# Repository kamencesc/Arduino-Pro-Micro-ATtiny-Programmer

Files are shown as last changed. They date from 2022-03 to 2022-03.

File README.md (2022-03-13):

# Arduino Pro Micro ATtiny85 Programmer
Board to program ATtiny85 using an Arduino Pro Micro.

It fits on two diferent size of Pro Micro (you can differenciate them by the USB, Mini USB for the big one and Micro USB for the little one).

Project comes from [Programming ATtiny85 with Arduino Uno ](https://create.arduino.cc/projecthub/arjun/programming-attiny85-with-arduino-uno-afb829) and it's adapted to Arduino Pro Micro, maybe needs some code modification (todo).

There are *OPTIONAL* LEDs as you can see in ~~[Utiliza tu placa Arduino como programador para ATtiny](https://fabricadigital.org/tutoriales/utiliza-tu-placa-arduino-como-programador-para-attiny/)~~ [Arduino as ISP and Arduino Bootloaders](https://docs.arduino.cc/built-in-examples/arduino-isp/ArduinoISP).

|LED|COLOR|FUNTION|
| -- | -- | -- |
|Top|Green|Heartbeat|
|Middle \*|Red|Error|
|Bottom \*|Yellow|Programming|

\* optional

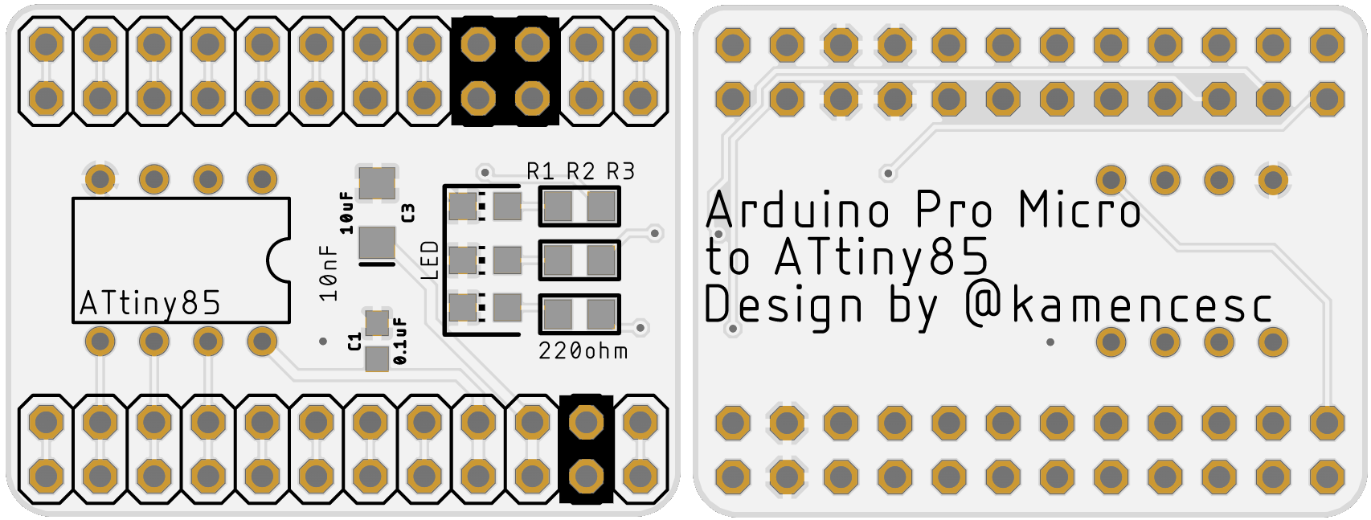
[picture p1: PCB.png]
PCB


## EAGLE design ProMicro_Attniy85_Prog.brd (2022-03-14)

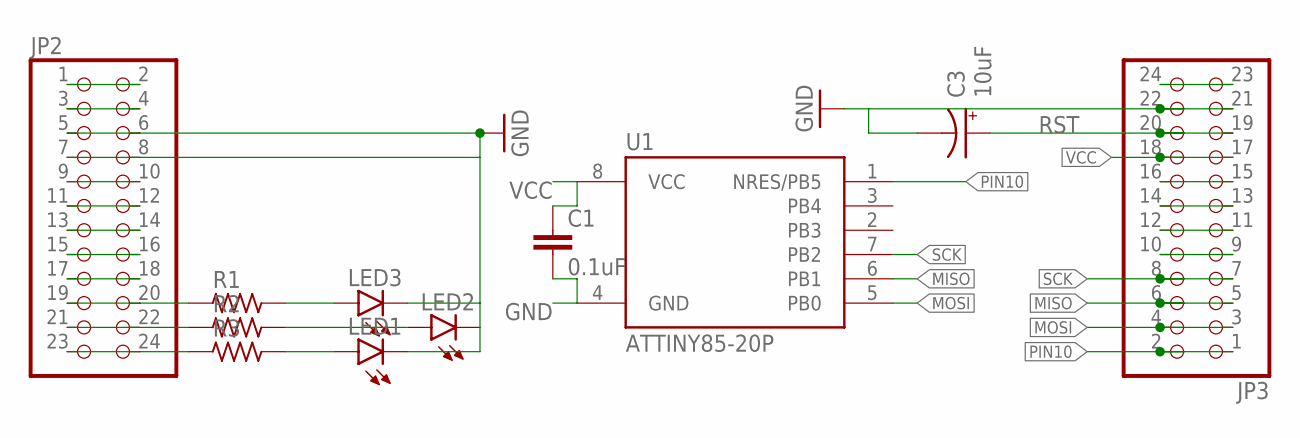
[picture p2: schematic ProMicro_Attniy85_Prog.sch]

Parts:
C1: 0.1uF; 0603
C3: 10uF; EIA3216
JP2, JP3: PINHD-2X12; 2X12
LED1, LED2, LED3: LEDCHIP-LED0805; CHIP-LED0805
R1, R2, R3: R_0805; R0805
U1: ATTINY85-20P; PDIP08_300MIL

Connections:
GND: C1.2, C3.-, JP2.5, JP2.6, JP2.7, JP2.8, JP3.21, JP3.22, LED1.C, LED2.C, LED3.C, U1.4 (GND)
MISO: JP3.5, JP3.6, U1.6 (PB1)
MOSI: JP3.3, JP3.4, U1.5 (PB0)
unnamed: JP2.1, JP2.2
unnamed: JP2.3, JP2.4
unnamed: JP2.9, JP2.10
unnamed: JP2.11, JP2.12
unnamed: JP2.13, JP2.14
unnamed: JP2.15, JP2.16
unnamed: JP2.17, JP2.18
unnamed: LED3.A, R1.2
unnamed: LED2.A, R2.2
unnamed: LED1.A, R3.2
unnamed: JP3.9, JP3.10
unnamed: JP3.11, JP3.12
unnamed: JP3.13, JP3.14
unnamed: JP3.15, JP3.16
unnamed: JP3.23, JP3.24
PIN7: JP2.19, JP2.20, R1.1
PIN8: JP2.21, JP2.22, R2.1
PIN9: JP2.23, JP2.24, R3.1
PIN10: JP3.1, JP3.2, U1.1 (NRES/PB5)
RST: C3.+, JP3.19, JP3.20
SCK: JP3.7, JP3.8, U1.7 (PB2)
VCC: C1.1, JP3.17, JP3.18, U1.8 (VCC)

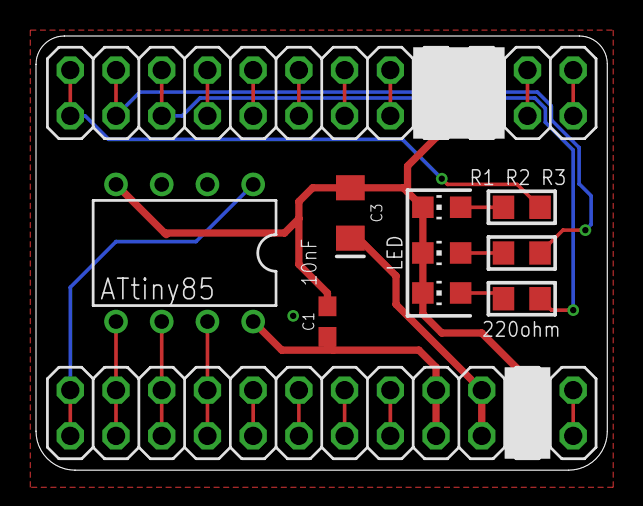
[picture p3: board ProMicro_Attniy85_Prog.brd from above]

Board: 2 copper layers, 31.7 x 24.1 mm, 11 parts (0 on the bottom side), 25 nets.

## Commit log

2019-07-26 Add files via upload
    V1
    [ProMicro_Attniy85_Prog.brd, ProMicro_Attniy85_Prog.sch]
2019-07-26 Add files via upload
    LEDs added following the desing in [Utiliza tu placa Arduino como programador para ATtiny]https://fabricadigital.org/tutoriales/utiliza-tu-placa-arduino-como-programador-para-attiny/
    [ProMicro_Attniy85_Prog.brd, ProMicro_Attniy85_Prog.sch]
2019-07-26 Add files via upload
    minor changes
    [ProMicro_Attniy85_Prog.brd, ProMicro_Attniy85_Prog.sch]
2019-07-26 Add files via upload
    pcb update
2019-08-12 Add files via upload
    Wrong size, corrected... the old one only fits on the original pro micro with micro USB
    [ProMicro_Attniy85_Prog.brd]
2022-03-12 Update README.md
    LED Info updated, broken links.
2022-03-14 Add files via upload
    As a recommendation from the AttinyCore85 Documentation, I've exchanged the capacitor (that was low) to an tantalum polar 100uf, and added another one of 0.1uf as coupler.
    [ProMicro_Attniy85_Prog.brd, ProMicro_Attniy85_Prog.sch]

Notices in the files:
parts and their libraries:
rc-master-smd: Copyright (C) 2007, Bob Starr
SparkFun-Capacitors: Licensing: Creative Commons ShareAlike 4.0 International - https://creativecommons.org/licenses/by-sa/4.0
